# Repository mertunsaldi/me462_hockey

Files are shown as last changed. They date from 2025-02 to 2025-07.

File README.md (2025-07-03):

# me462_hockey

## Hafta puanları

| Weeks | Date | Mert | Fatih | Tuna | Seçkin | Bekirhan |
|---|---|---|---|---|---|---|
| 3 | 06.03.2025 | 4 | 4 | 4 | 4 | 4 |
| 4 | 13.03.2025 | 7.5  | 6.5 | 6 | 7.5 | 7.5 |
| 5 | 20.03.2025 | 6  | 6 | 6 | 6 | 6.5 |
| 6 | 27.03.2025 |  7 |  6.5  | 6.5 | 5 | 6.5 |
| 7-8 | 10.04.2025 |  5 | 4 |6 | 4 | 3 |
| 9 | 17.04.2025 |  6.5 | 7 |6.5 |  7.5 | 6 |
| 10 | 24.04.2025 |  6 | 6 |7.5 | 6 | 6 |
| 11-12 | 08.05.2025 |  7.5 | 7 | 8.5 |  7 | 7 |
| 13 | 15.05.2025 |  8 | | 9 | 7  | 9 |  
| 14 | 22.05.2025 |  7.5 | |7 | 7  | 8 |  
| | 19.06.2025 | | | 6| | 9 |

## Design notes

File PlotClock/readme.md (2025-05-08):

The original project by https://github.com/ProjectsWithRed/plotclock?tab=readme-ov-file is being modified.

To do (17.04.2025):   
  
Done:
- Try the micropython code on the real setup (tick)
- If you can't make it work after calibration, you can use ESP32 and the original code. (tick, calibration is done)
- Maybe add a 3rd dof for rotation at the end effector with another servo so that you can adjust the angle of the impact surface. (tick, seems like not needed)
- Assemble the whole mechanism and try mode 1. (tick, small design changes and modifications to code are done)
    
To be done:
- 0,0 noktasinin yerini ve workspace'ini tam olarak belirle (Hangi koseye uzanabiliyor ve konumu ne vs.) Kodda da bu duzgun bir sekilde map edilmis olmali. Workspace'im dikdortgen degil. Bir 5bar simulasyonu yapip tam olarak workspace'imi bulmaliyim. Sonra o workspace'i mi kullanicam yoksa consistent oldugu dusundugum x ve y ranglerinin icinde mi calisicam ona karar vermeliyim.
- Try going to the desired location in a simulation environment. (tick)
- Add a ball and target location to the simulation and integrate the search according to the ball and target location.
- Serial communication with the master and moving to the location (and angle of the impact surface) received by the master computer.
- Modify the design slightly. Remove the whiteboard, add legs, etc.

Notes:
- Su an 0,10 diyince y'de 0'a geliyor. 0,5 diyince servo baseini donduruyor o yuzden y=10 benim sifirim olmali. 0,10 ile  0,20 arasinda yaklasik 11mm mesafe var. Boyle bir errorum var gibi duruyor.
- Bu map range tam istedigim gibi calismiyor, tam ne ise yapiyor anlayamadim hatta cunku belli x yada y degerinin otesine gitmesini engellemiyor. Sanirim sadece potansiyometreyi daha accurate maplemek icin var.

The mechanism:


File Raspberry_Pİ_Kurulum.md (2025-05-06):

Raspberry Pi Bilgileri Ve kurulum rehberi <br>

  hostname: raspberrypi.local <br>
  username: remor <br>
  password: remor <br>

Wireless LAN
  
  SSID: Seççavv <br>
  Password: mersin3301 <br>

Kurulum ve RaspberryPi kullanma

1) Pi'a güç verin
2) Bilgisayar ve Pi'ı aynı internet ağına bağlayın
3) Bilgisayardan terminali açın ve aşağıdaki komutu girin. (username@hostname)
  ssh remor@raspberrypi.local
4) Şu an pi'ın içindesiniz.

Eğer Pi'dan masaüstü görüntüsünü almak isterseniz
1) Pi'ın masaüstü görüntüsünü almak için terminale sudo raspi-config yazın
2) Interface optionsa girip VNC serverını enablelayın
3) Internetten VNC Viewer adlı uygulamayı indirin ve kurun
4) VNC Viewera pi'ın bağlı olduğu ipyi yazarsanız kendi bilgisayarınızda pi'ın masaüstünü görebilirsiniz

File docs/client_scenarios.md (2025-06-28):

# Writing Client Scenarios

Clients may upload their own Python modules implementing custom logic. Each file must define a `ClientScenario` class derived from `ball_example.scenarios.Scenario`.

```python
from ball_example.scenarios import Scenario

class ClientScenario(Scenario):
    def update(self, detections):
        # access PlotClock helpers or run your own logic
        pass
```

Use `/load_scenario` to activate the scenario:

```bash
curl -X POST http://localhost:8000/load_scenario -H 'Content-Type: application/json' -d '{"path": "my_scenario.py"}'
```

Alternatively upload the file:

```bash
curl -X POST -F 'file=@my_scenario.py' http://localhost:8000/load_scenario
```

You can send runtime messages to the active scenario with `/send_message`:

```bash
curl -X POST http://localhost:8000/send_message -H 'Content-Type: application/json' -d '{"mode": "stop_defense"}'
```

**Security warning:** the server executes the uploaded Python code directly. Only run scenarios from trusted sources.

## Example: Standing Ball Hitter

The repository contains an example scenario in `examples/standing_hitter_client.py` which simply reuses the built-in `StandingBallHitter` logic.

1. Start the server on the host machine. You can either run the package or execute the script directly:
   ```bash
   # package form (recommended)
   python -m ball_example.app

   # or run the script directly
   python ball_example/app.py
   ```
2. From another terminal (or another machine on the same network) upload the scenario:
   ```bash
   curl -X POST -F 'file=@examples/ball_reflector_client.py' http://localhost:8000/load_scenario
   ```
3. Connect the PlotClock using the **Connect Pico** button (or POST to
   `/connect_pico`).  Ensure the Arena Manager marker (ID 0) and the PlotClock
   marker (ID 1) are visible to the camera while connecting.  Any additional
   PlotClock markers will be ignored. The button will turn green once the
   connection succeeds.
4. Open `http://<host-ip>:8000/` in a browser. After uploading the scenario,
   press **Start Scenario** (or POST to `/start_scenario`) to begin execution.
   When a scenario starts, its `on_start()` method runs. The built-in
   `StandingBallHitter` clears any previous calibration so you should see the
   calibration routine whenever you start it.  Calibration points are now
   chosen slightly inside the working area so the arm doesn't hit its
   mechanical limits.
5. Optionally send messages while it is running:
   ```bash
   curl -X POST http://localhost:8000/send_message -H 'Content-Type: application/json' -d '{"cmd": "stop"}'
   ```

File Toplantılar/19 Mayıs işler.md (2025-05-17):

19 Mayıs haftası için:

PiCam kullanma
Dİnamik takip
MAsa boyutları kararlaştırma
Mikroswitchler

Sonrası için

Plot clock yukarı almak
Plot clock link length kararlaştırmak

To do:

- plotclock buyuyecek
    - yeni linklerin boyunun belirlenmesi
        - arena boyunun yarisini taramali mesela. Bunun icin projectoru belli bir yukseklige cikarip nasil bir arena boyu olabilir denenmeli.
        - ya bekirhanin geogebrasinda ya da tunanin simulasyonda denenerek link lengthler belirlenebilir.
    - link tasarimi guncellenmesi, yeni servoya gore
    - baski
    - yeni servonun harika hanimdan alinmasi
    - assembly
    - kodda link lengthlerin guncellenmesi
    - kalibrasyonun yapilmasi ve kodun denenmesi
- plotclock daha yukari takilacak, altindan top gecip duvara carpabilmeli.
- duvar yuksekligi kisaltilacak (çok zor değil, çok gerekli de değil)
  
- microswitch ile carpma sensoru yapilcak
- top statikken detection gelistirilmeli.

Yeni hafta için yapılacaklar

Plot clock büyütme
	
	Yeni link boyutu belirlenmesi
	Kodumuz link length değişimine uygun
	Plot clockucu elektromıknatıs olabilir,

Arena Boyutumuz?
	Projektörü sigmaya eklenemk için kesim
 
 Seckin -> pi ve pi kamerasiyla detection deneyecek pazar sabahina kadar.
Mert- > Seckinden kamera ve pi devralip, pi kamerasiyla ball detection gelistirilecek.
Bekirhan, Tuna -> Arena ve yeni link boyu belirlenmesi, yeni link tasarimi, baski, assembly, ve calistirilmasi.
Fatih -> duvar yuksekligi 6cmye dusurulup uretilebildigi kadar uretilicek

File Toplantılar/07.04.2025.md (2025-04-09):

- Tuna'nın duvar tasarımına bakıldı
- Bekirhan'ın shift register demosuna bakıldı, resistor fikri incelenecek
- İş bölümü yapılacak
- Fatih'in duvar tasarımı bittikten sonra decision matrix ilenihai tasarım belirlenecek

# İş bölümü

## İşler

- Flowchart çizilecek (input output belirleme)
- Detaylı duvar tasarımı/üretimi -> Fatih, Tuna
- Bağlantı arayüzü belirleme -> Bekirhan, Seçkin
- Projeksiyon ve image beraber çalışıyor mu? Her ortamda çalışıyor mu? Çalışmazsa projeksiyonu ekarte mi etsek? -> Perşembe dersten sonra
- Gadget tasarımına başlanacak -> Tuna (5 bar robot), Seçkin, Fatih
- OOP için kod iskeleti -> Mert, Tuna
  - Classlar ve inheritance ilişkisi 
  - Methodların input outputları
  - Init parametreleri
- Touch sensor seçeneklerinin belirlenmesi -> Bekirhan, Mert

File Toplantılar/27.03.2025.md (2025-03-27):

Tarih 27.03.2025
Katılımcılar: Tüm Grup Üyeleri

Toplantı Konuşulanlar:

1) Blockly konuşuldu.

2) Plot clock hakkında konuşuldu.

3) Duvar Tasarımları:

	- Tasarım matrisi yapın ve karar verin
	- Fatihin Tasarımı
		- Hinge tasarımı düzenlenerek bağlantı ksıımalrındaki gap yok edilebilir.
	
	- Seçkinin Tasarımı
		- Oynar olması çok da önemli mi? sorusu soruldu.
		- T şeklinde duvar sıkıntı olur mu dendi.
	- Tork anahtarı çalışma mantığına bakılabilir.

	- Duvar ayakları fikri konuşuldu beğenildi.

	- Kablolama işi ic232 kullanıabilir.
	- Duvarların hepisi bağlı olması yerine her gadget etrafını okusa
	- Dirençler ile birlikte sensörler okunabilir.
	- Optik sensör kullanılabilir. ve bir köprü yapılabilir.
	
Hedefler:
- Tatil boyunca birbirinden farklı birkaç oyun için blockly denenebilir. Fikir olmaması açısından.
- Birkaç senaryo için algoritma çıkarılacak.
- Adreslemenin nasıl yapılacağı belirlenecek
 - Shift register
 - Farklı resistorler, farklı duvarlara
 - Gadgetlara da pico ekleyip zinciri her bir picodan sonra tekrar oluşturmak
- Duvar Tasarımını belirlenecek artık. tasarım matrisi yapılacak.
- Yazılım kısmına başlanacak

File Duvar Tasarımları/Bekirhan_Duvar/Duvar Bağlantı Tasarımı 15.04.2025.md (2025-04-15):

# Genel Güç Hattı
- 5V ve GND kabloları tüm duvarların içinden geçerek birbirleriyle bağlanacak.

# Actuatör Bağlantı Sistemi Tasarımı

## 1. Her actuatörün kendi mikroişlemcisi olacak.
- Mikroişlemci yalnızca ana bilgisayara bağlanacak.
- Tercihen sadece iki ekstra kablo ile bağlantı yapılabilecek (I2C ya da UART gibi; 5V ve GND zaten mevcut) ya da WiFi ile kablosuz bağlantı sağlanabilir (ancak hız yeterli olur mu???).

## 2. Her actuatör arenanın ana işlemcisi ile hareket ettirilecek.
- Kablolama daha karmaşık olacaktır, ancak SIPO tipi bir shift register kullanılabilir. Böylece tüm actuatörler minimum kablo sayısı ile kontrol edilebilir.
- SIPO ile PWM kontrolü verimli olmayabilir. Sinyalin manuel olarak PWM şeklinde oluşturulması gerekebilir.

## Sonuç
- Her actuatörün bir mikroişlemcisi olmasına karar verdik. Bunun sebebi, projenin bir eğitim ortamı oluşturmayı amaçlamasıdır. Böylece yeni bir gadget tasarımı, arena tasarımından mümkün olduğunca bağımsız şekilde yapılabilir.

## Mikroişlemciler Arasında Kablolu mu, Kablosuz Bir İletişim mi Kullanmalıyız?
- Her ne kadar hızlı bir top hareketi hedeflenmese de, topa vurma aksiyonunun gecikmeli olmasını istemiyoruz. Geçmiş deneyimlerden (örneğin ME461 projesi) WiFi’ın yeterli hıza ulaşamadığı anlaşılmış ve bu nedenle kablolu tasarım tercih edilmiştir.
- Kablolu haberleşme, WiFi seçeneğini tamamen dışlamaz. İstenirse her iki yöntem de uygulanabilir.

## Mikroişlemciler Arasında Hangi İletişim Protokolü Kullanılmalı?
- İlk başta I2C düşünülmüş, fakat yapılan araştırmalar sonucunda I2C’nin uzun kablolarda sorun çıkardığı öğrenilmiştir.
- UART da bir seçenek olarak değerlendirilebilir. Ayrıca yapay zekâ (AI) tarafından RS485 modülü kullanılması önerilmiştir.
- Nihayetinde, sadece 2 kablo ile tüm mikroişlemcileri birbirine bağlamak mümkün görünmektedir.

# Çarpma Sensörü Bağlantı Tasarımı

## Microswitch ya da 1/0 sinyali üreten başka bir birim kullanılacak.
- PISO tipi shift register kullanımı, 10.04.2025 tarihli toplantıda kabul edilmiştir.
- Load, Clock ve Data olmak üzere 3 kablo hattına ihtiyaç vardır.
- Bu hatlar aracılığıyla 1 ve 0 sinyali üreten diğer sensörler de okunabilir. Örneğin,daha önce konuşıulan içinden geçen topu temassız algılayan kızılötesi sensör de bu hatla okunabilir.

# Sonuç

- 5V, GND, Load, Clock, Data, ActuatorCom1 ve ActuatorCom2 olmak üzere minimum 7 adet kabloya ihtiyaç duyulmaktadır.

## T Şeklindeki Duvar Bağlantısı Sorunu

- Daisy-chain bağlantı yapısı tercih edildiğinden, bu yapı üçlü bağlantıyı (özellikle sensör veri kablosu için) desteklememektedir. Bu nedenle aşağıdaki alternatif çözüm yöntemleri değerlendirilmiştir:

### 1. İç Duvarlara Sensör Veri Kablosu Koymamak
- Adından da anlaşılacağı üzere, "sorunları sorun etmezsen sorun kalmaz" yaklaşımıdır.
- Ancak bu yaklaşım, iç duvarlardaki sensör verilerini alamamayı göze alır.

### 2. Sırt Sırta 2 Duvar Kullanarak İç Kısımlara Girmek
- Basit ve efektif bir yöntemdir.
- Ancak bu durumda ilgili bölgedeki duvar kalınlığı artacak ve bu durum simetrik bir duvar tasarımını desteklemeyebilir.

### 3. Sensör Veri Kablosu Sayısını Bir Adet Arttırıp Giriş-Çıkış Yapmak
- İç kısma giden duvarda iki veri kablosu kullanılıp, en uç noktada bu iki kablo birleştirilerek “U” yapısı oluşturulur.
- Bu şekilde toplamda 8 kabloya sahip olunur (bu sayı, konektör standardizasyonu açısından da daha uygun olabilir).
- Sıklıkla kullanılmayan bu ekstra kablo, gelecekte farklı amaçlarla da kullanılabilir. Örneğin:
  - İki duvarlı bir gadget tasarımında, bir mikroişlemci ile diğer duvardaki bir servo motor kontrol edilebilir.

##  Ada Şeklindeki Duvar Bağlantı Sorunu
- Daisy chain yapısı nedeniyle, arenanın dış duvarlarıyla fiziksel bağlantısı olmayan “ada” tipi duvarlar sıkıntı yaratmakta.
### 1. Ada duvarlarında gadget veya sensör olmasın
  - Düşünülebilir ama meh gibi de

### 2. Köprü denen bağlantı elemanı
  - Yalnızca kablo bağlantısı için duvarları birbirine bağlayan altından topun geçmesine müsade eden bir eleman
    
# Connector Seçimi
- Her duvarı birleştiren konnectör ve duvarın üstündeki gadget ve sensör bağlantı connectörü aynı cins olabilir böylece karşıklığın önüne geçmiş oluruz.
- Duvarla T çiziyorsak eğer her duvarı bir öncekine bağlamamız yeterli eğer ekstra data kablosu kullanılacaksa y yapılan yerdeki konnectörün fakrlı olması gerekecek.
- Her duvara çarpma sensörü eklenebielcekmiş gibi tasarım yaptığımızdan dolayı eğer duvarda sensör takılı değilse duvarın sağı ve soluna bağlanan data kablosu shortlanmalı. Eğer duvarda gadget ve sensör yoksa basit bir U şekilnde pin takılı kalabilir.
- Gadgetlar yalnızca 4 (eğer ekstra kablo da dahil edilecekse 5) pine ihtiyaç duyuyor. Duvarın üstündeki 8 pine geçebilen 4 pinli bir yapı düşünülebilir (OverEnginnering olabilir)

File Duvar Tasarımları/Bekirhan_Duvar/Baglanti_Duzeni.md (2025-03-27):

Amaç: Modüler bir duvar sisteminin sensör ve actuatörleri için uygun bağlantı yöntemimi bulmak.

Gereklilikler:
- Karışıklılığı ve gelecekteki kullanımının kolaylaştırılması için kablo sayısının azaltılması.

Çözüm Önerileri:
1) Her sensör ve actuatöre micrprocessörden bir kablo çekmek (Kötü çözüm. her duvar arasında 15-20 pinlik bağlantı gerekir ve hangi sensörün hangi kabloya takıldığını kontrol etmek zor.)
2) Shift register kullanarak az bir bağlantı sayısıyla işi hallettmek.

---
Shift Register kullanımı
  - 2 Çeşit shift register var piso (Parallel input serial output) ve sipo (Serial input parallel output)
  - Piso type birden fazla sensörü tek bir gpio pin ile okumaya yarıyor. Her bir clock sinyalinde paralel olarak yüklenmiş sinyal sırasıyla serial outputa iletiliyor.
      - Her bir duvarın içine bir adet piso type shift register konularak tüm sensörleri 3 kabloyla okuyabiliriz. (data, clock, load). 
  - Sipo type ile de birden fazla actuatör kontrol edilebilir. Maalesef pwm sinyali kullanılmak isteendiğinde manuel olarak oluşturulmak gerekecek.
      - Pwm kullanılmak istenirse PCA9685 16 Kanal i2c PWM/Servo Sürücü gibi bir sürücü kullanılabilir ama her gadget için bir tane kullanmak pahalı olabilir.

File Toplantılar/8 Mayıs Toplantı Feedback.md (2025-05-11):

8 Mayıs Toplantı Feedbacki

Duvar tasarımı onaylandı

Projeksiyonlu ve projeksiyonsuz usecaseler nasıl olabilir?
	Projeksiyon çok yukarıda olması gerektiği için ne yapabiliriz diye düşünüldü
		çünkü fiziksel zorluklar var
	
Alta ekran olsa nasıl olacak?
		ekran daha net olucak

Raspberry Pi konuşuldu

Simulasyon konuşuldu
	Hoca beğedndi
Görüntü işleme konuşuldu		

Elimizde ne varsa onun senaryosunu çıkarmaya çalışalım

Haftaya hedefimiz:

* Statik bir top duruyor, istediğimiz yere koyuyoruz
* Hedef Aruco marker veriliyor
* Plot clock ona göre vuruyor
* Eğer aruco markerın içine girerse kazanmış oluyoruz

19 Mayıs Hedefimiz

* Dinamik sistemi vurmak 

Sigmaları masaya geçirelim, öyle ilerleyelim

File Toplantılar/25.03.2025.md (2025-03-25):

Toplantı Başlangıç Saati 18:00
Toplantı Bitiş Saati 19:45
Toplantı Katılımcıları:
Bekirhan Canbaba
Fatih Can
Mert Ünsaldı
Tuna Kızal
Seçkin Eroğlu

			Toplantı Konuları

			1) Duvar Tasarımlarının Değerlendirilmesi
			2) Google blockly hakkında bilgilendirilme.

1) Duvar Tasarımlarının Değerlendirilmesi

a) Seçkinin RIGID tasarımı
	Seçkinin tasarımı rigid + ama flexible değil mecazen o kadar esnek bir tasarım değil. Farklı açıda birleşimler için oan göre önceden tasarlanmış duvara ihtiyaç var.

b) Fatihin Tasarımı
	Her açıya uygun duvar tasarımı, Duvar bileşim yerlerinde gap var düz olması tercih edilir. Elektrik bağlantısı daha belirlenmemiş.

c) Mertin Tasarımı
	Hem bağlantı elemanı hem de kablo için bir arayüz. Farklı açılara uyumlu ama Fatihinkinde olduğu gibi duvar birleşim yerlerinde gapler var.

d) Bekirin Tasarımı
	Ölü doğdu Fatihinki tüm özelliklerini zaten karşılıyor.

Arada boşluk kalma sorununa continious piano hinge: Sorunu diğer tarafa açılmıyor

2) Google blockly hakkında bilgilendirilme.
Mert bakmış lakin düşünüldüğü kadar implemente etmesi kolay değilmiş. Node-Red adında aynı mantıkla çalışan başka bir program varmış. İlerde bakılacak. 

Hedefler:
1) Shift Register ile daisy chain işi araştıralacak.
2) Fatihin modüler ayak fikrine bakılcak. Böylece birden fazla yüzey (sigma profile mdf gibi)
3) Plot clock alternatifleri araştırılacak

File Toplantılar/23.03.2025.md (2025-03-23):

Toplantı Başlangıç Saati 12.00

Toplantı Bitiş Saati 13.20

Toplantı Katılımcıları:
- Bekirhan Canbaba
- Fatih Can
- Mert Ünsaldı
- Tuna Kızal
- Seçkin Eroğlu

Toplanti Konulari:
- Sensörlerin belirlenmesi
- Konnektör tasarımı hakkında fikirler
- Duvar tasarımı hakkına fikirler
- Bu hafta için iş bölümü

## Duvar tasarımları
- Düz duvar ve içinde elektronik olan duvarlar ayrı ayrı olabilir
- İçinde elektronik olan tek bir duvar yapılıp içi boş da basılabilir
- Ayaklar modüler olabilir

## Sensörler

- Haptic/impact sensörü takılıp çıkarılabilir yapılabilir.
- Hazır sensörler araştırılacak
- Kendimiz sensör yapabilir miyiz?

## Konnektör tasarımları
- Pogo connectors
- Konnektör açıları sabit tutulup duvarlar açılı basılabilir
- Yukarıdan ters U şeklinde 

## Bu hafta için iş bölümü

Mert: Blockly
Seçkin, Bekirhan, Fatih, Tuna: Duvar
Bekirhan: Top yuvarlayacak

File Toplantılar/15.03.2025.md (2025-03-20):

Toplantı Başlangıç Saati 15.30

Toplantı Bitiş Saati 18:15

Toplantı Katılımcıları:
- Bekirhan Canbaba
- Fatih Can
- Mert Ünsaldı
- Tuna Kızal
- Seçkin Eroğlu

Toplanti Konulari:
- Top ve puck karsilastirmasi
- Gecen yilin air hockey masasinin detayli incelenmesi

Ball advantages:
-	Degisken yuzeylerde kullanilabilir
-	Air’ a gerek yok (pompa/fan, delikli ve duz yuzeye gerek kalmiyor). Air hockey table yapmak gorece buyuk bir is.
-	Farki kutlelerde top kullanimi puck’a gore daha rahat
-	Belki iste

Ball disadvantages:
-	Arenadan disari cikabilir
-	Tam ortadan vurulmadigi surece spin alabilir ve bu spin sekmeleri hesaplamayi zorlastiriyor.
-	Puck’da yaptigmiz gibi dead zone olusturmak daha zor. Belki magnetic bir sey ile yapilabilir. (Bakugan :D)
-	Duvara carpinca donme yonu tam tersine donuyor, enerji kaybi.

Puck advantages:
-	Surtunmesiz yuzey, daha uzun mesafeler kat edilebilir
-	Silindire vurmak daha kolay, cunku silindirin merkezine herhangi bir yukseklikte vurabilirsin. Topa gore daha cok vurma yerin var.

Puck disadvantages:
-	Masa gerekiyor!!! -> table’s disadvantages demek aslinda
-	Variable surtunme yapamiyorsun.

Brainstorming:
-	Duvarlarin arasindaki alanin egimi mukemmel olmayabilir. Bunu search algorithmasina entegre etmemiz gerekebilir. Bunun icin duvarlara egimi olcebilecegimiz sensorler entegre ederiz (mesela karsilikli 4 duvara) ve measurmentlari kullanarak belli bolgelerin egimlerini algoritmaya entergre edebiliriz. 
-	Yuzeyin surtunme katsayisini ogrenmek icin bir deneme atisi yapilabilir. Topu iteriz ve durma suresine gore surtunme katsayisi hakkinda bilgimiz olmus olur.
-	Duvar nasil yerde sabit duracak?
o	Vakum aparati (vantuz gibi bir sey) -> her yuzeyde kullanilamaz
o	Agirlik eklemek
o	Dis tarafinda bir cikinti, darbe geldigin
o	Laptop altlarindaki padler  ya da multi-layer cift tarafli bant
-	Telescopic ayaklari olan kameranin yerlestirilecegi U seklinde bir kamera tutacagi. U’nun her kenarinin uzunlugunun ayarlanabilmesi gerekiyor, arenanin boyutunu degistirmek istiyorsak.
-	Duvarlarin mockup tasarimlarinin dusunulmesi gerekiyor. Electrical and physical connections etc. 
-	Duvara top carpti, peki hangi duvara carpti bunu nasil anlayacagiz? Bunun icin neopixel strip mantigi kullanilabilir.
-	Spin cok buyuk sorun cikartirsa ball transfer unit kullanilarak bir objeyi de kullanabiliriz. 
-	Google blockly kullanarak oyun, arena set-up isleri halledilebilir. GUI’de duvarlari yerlestirdikten sonra istedigimiz modulun ustune surukle birakla gadget atayabiliriz. 
-

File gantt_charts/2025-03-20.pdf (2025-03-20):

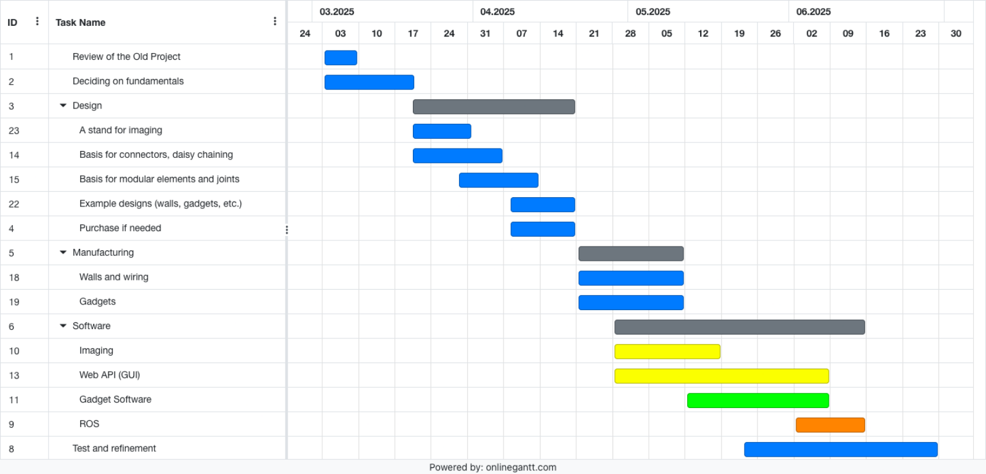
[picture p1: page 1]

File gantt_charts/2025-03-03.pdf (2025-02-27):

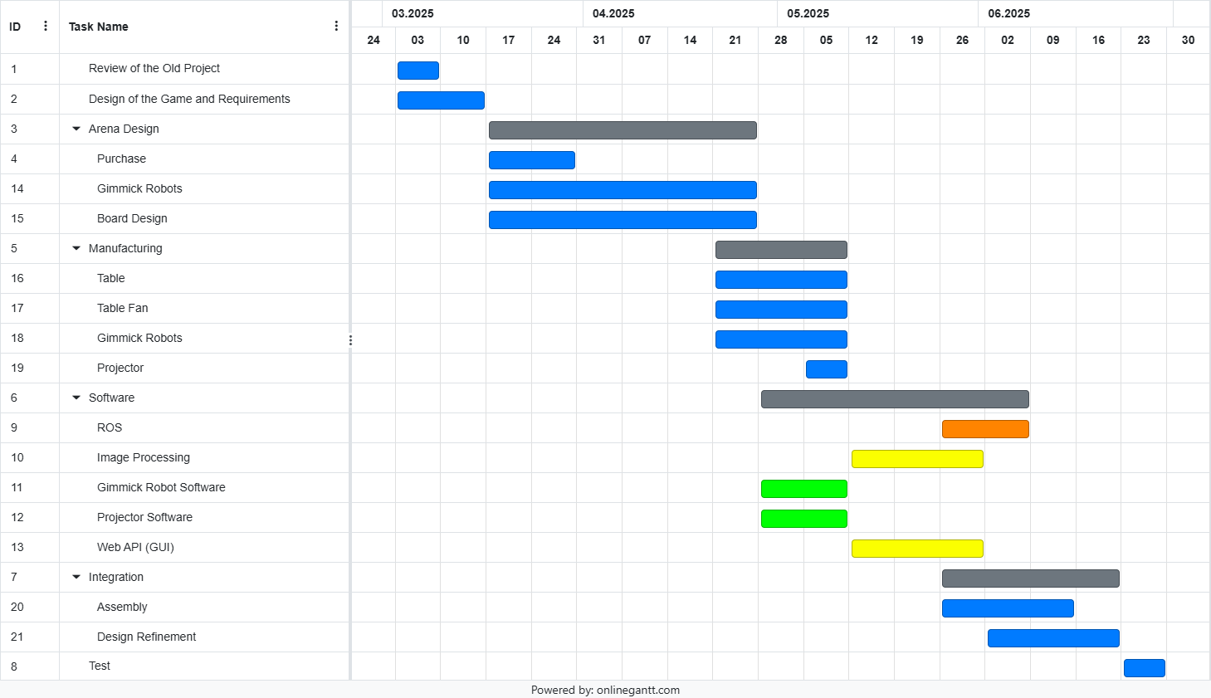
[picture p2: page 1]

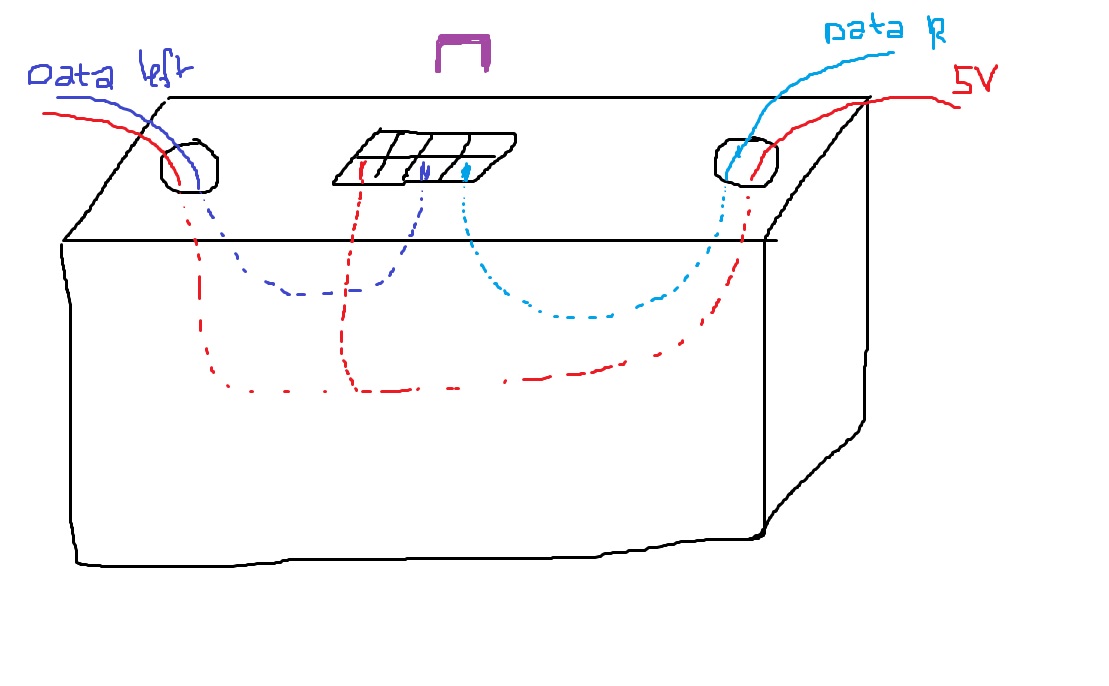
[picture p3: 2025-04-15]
Duvar Tasarımları/Bekirhan_Duvar/DuvarBaglantiOrnegi.jpg

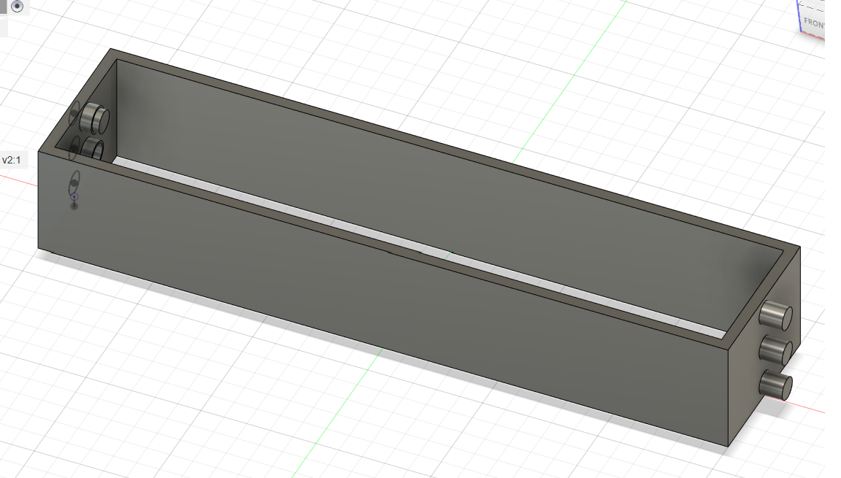
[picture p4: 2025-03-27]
Duvar Tasarımları/Seckin/Duvar.png

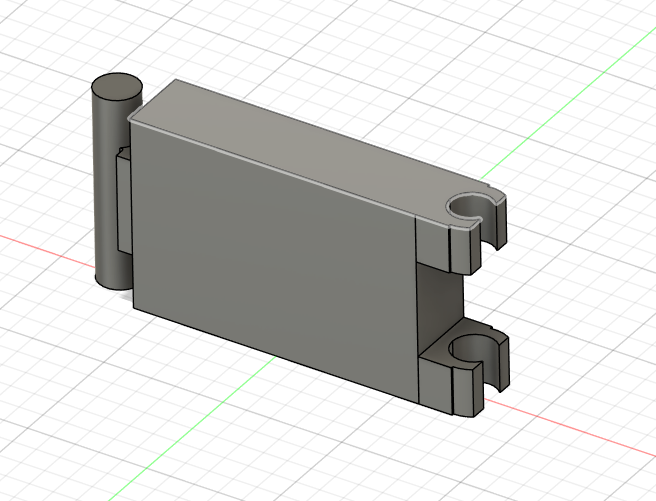
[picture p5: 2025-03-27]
Duvar Tasarımları/Fatih/TEk_iso.png

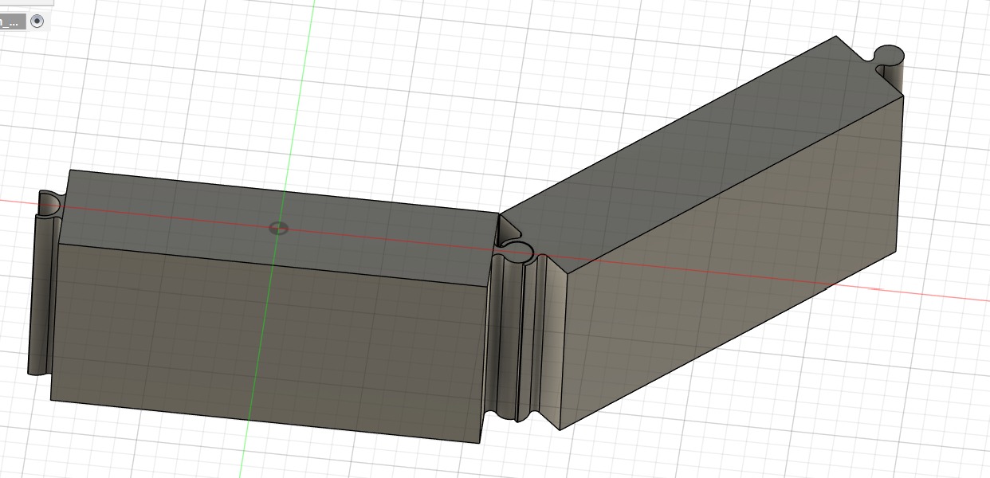
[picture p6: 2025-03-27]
Duvar Tasarımları/Bekirhan_Duvar/Bekirhan_Duvar_Tasarimi/Duvar_Tasarimi_Bekirin_Fikri_Iso_View.jpg

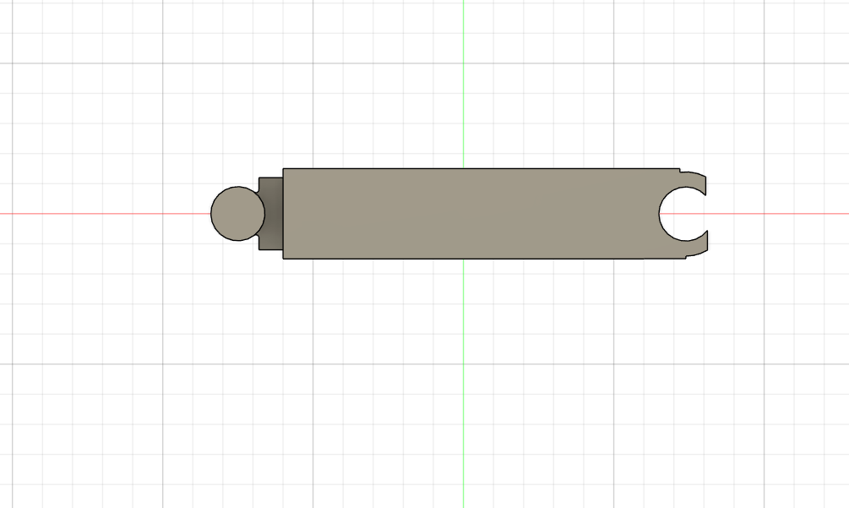
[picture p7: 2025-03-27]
Duvar Tasarımları/Fatih/tek_top.png

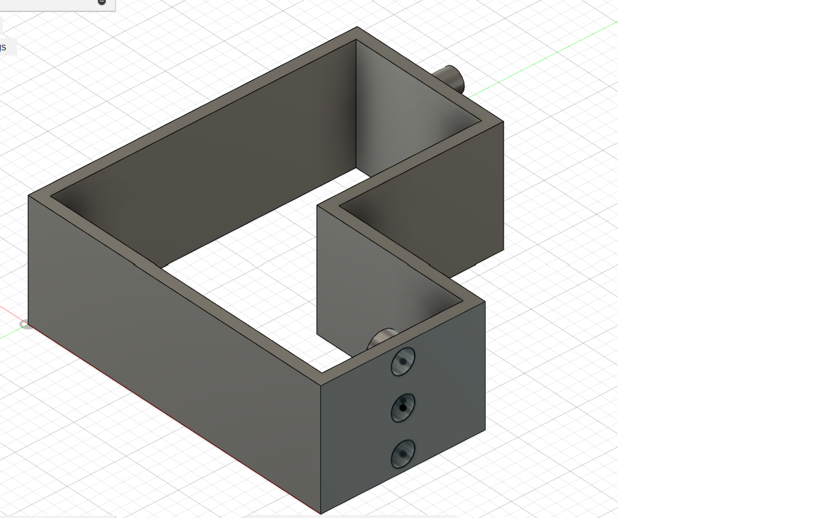
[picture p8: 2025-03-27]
Duvar Tasarımları/Seckin/Kose.png

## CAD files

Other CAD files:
PlotClockDesign/BigPlotClock/LinkHead.f3d
PlotClockDesign/BigPlotClock/servoHolderParametrized.f3z
PlotClockDesign/SmallPlotClock/PlotClockServoHolder v2.f3d
PlotClockDesign/SmallPlotClock/SmallPCLink.f3d

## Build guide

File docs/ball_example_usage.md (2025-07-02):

# Ball Example Overview

This document explains how to use the `ball_example` module, how to run the provided Flask server, and how you can build your own user interface and scenarios. After reading this guide you should be able to develop a new application around the core API.

## Running the Server

The repository ships with a ready-to-use Flask application located in `ball_example/app.py`. Start it either as a module or by executing the script directly:

```bash
python -m ball_example.app     
# or
python ball_example/app.py
```

By default the server listens on `{your_ip}:8000` and begins processing frames from camera index 0. The web interface served at `/` shows the live video with all detections overlaid. Also, `{your_ip}:8000/debug` shows information about detections and object properties.

Note: `{your_ip}:8000/tune` shows a masked frame, which does NOT represent the one used for detecting balls.

The server exposes several endpoints used by the JavaScript front end (see `templates/` and `static/`). The most important ones are:

- `POST /connect_pico` – scan for PlotClock devices and build the default scenario when marker 0 and 1 are present.
- `POST /start_scenario` – activate whichever scenario was previously loaded.
- `POST /stop_scenario` – stop the running scenario.
- `POST /load_commands` – load a list of high level commands.
- `POST /load_scenario` – load a Python file defining a `ClientScenario` (see below).
- `POST /send_message` – send an ad-hoc message to the active scenario.
- `GET /debug_data` – retrieve extended diagnostics returned by `GameAPI.debug_info()`.

Refer to `docs/api_testing_guide.md` for examples of how to call these endpoints from another machine.

### Example Workflow

1. Flash `PlotClockMaster.py` to the master Pico and the appropriate
   firmware (`PlotClockSlave.py` or `arena_manager_slave.py`) to each
   device.
2. Connect the master Pico to your PC via USB and run the server:

   ```bash
   python -m ball_example.app
   ```
3. Use the web UI or POST to `/connect_pico` to detect the attached
   devices.
4. Upload a command list with `/load_commands` or a custom scenario with
   `/load_scenario`.
5. Start execution via `/start_scenario` and open
   `http://<host-ip>:8000/` in your browser to view the stream and
   overlays.

## Key Classes

### `GameAPI`

`GameAPI` owns the camera, tracking pipelines and the currently active scenario. The Flask app only acts as a thin wrapper around this class. Important methods include:

- `start()` – start the camera and pipelines.
- `set_cam_source(src, width, height, fourcc)` – switch the camera source.
- `connect_pico()` – open the serial connection to the Pico master and detect PlotClocks.
- `load_commands(commands)` – create a `CommandScenario` from a list of dictionaries.
- `load_scenario(path)` – load a Python module that defines `ClientScenario`.
- `start_scenario()` / `stop_scenario()` – control the currently loaded scenario.
- `start_clock_mode(clock, mode, target_mm)` – start an action like `attack`, `defend` or `hit_standing` for a single PlotClock.
- `start_move_object(manager, obj, target_mm)` – create a `MoveObject` scenario to move a ball or obstacle.
- `debug_info()` – return dictionaries describing all detections and parameters.

A GUI can simply instantiate `GameAPI`, call `start()` and then display `get_annotated_frame()` in a loop.

### `PlotClock` and `ArenaManager`

Both classes live in `ball_example/gadgets.py` and encapsulate communication with the robot hardware. `PlotClock` controls a hitting arm while `ArenaManager` can also grip and move objects. Their `calibrate()` methods expect lists of ArUco detections and drive the internal calibration FSM.

Useful helpers are:

- `send_command(cmd)` – send raw firmware commands.
- `pixel_to_mm()` / `mm_to_pixel()` – convert between image pixels and robot coordinates once calibrated.
- `draw_working_area(frame)` – draw the reachable polygon for visualisation.
- Behaviour helpers such as `attack()`, `defend()` and `hit_standing_ball()` which construct corresponding scenarios.

### Scenarios

Every scenario derives from the base class `ball_example.scenarios.Scenario` which defines the lifecycle hooks:

```python
class Scenario:
    finished: bool = False
    def on_start(self):
        pass
    def on_stop(self):
        pass
    def process_message(self, message: dict):
        pass
    def update(self, detections):
        raise NotImplementedError
```

Built-in scenarios in `scenarios.py` implement more complex behaviours. Notable ones are:

- `MoveBallHitRandom` – moves the ball to the hitter and then strikes it toward a random target.
- `StandingBallHitter` and `SingleHitStandingBallHitter` – wait for a ball to stop then hit it toward a provided point.
- `BallReflector` – defend the goal by reflecting incoming balls.
- `MoveObject` – used by `ArenaManager` to grab and place objects.

All scenarios provide overlay callbacks (`get_line_points`, `get_extra_points`, `get_extra_labels`) used by the web UI for drawing helper graphics.

## Writing Your Own Scenario

Create a new Python file defining a subclass named `ClientScenario`. You can import any helpers from `ball_example`:

```python
from ball_example.scenarios import Scenario
from ball_example.gadgets import PlotClock

class ClientScenario(Scenario):
    def __init__(self, clock: PlotClock, frame_size):
        self.clock = clock
        self.frame_size = frame_size

    def update(self, detections):
        # Implement your frame logic here
        pass
```

Load the file at runtime using:

```bash
curl -X POST http://localhost:8000/load_scenario -F 'file=@myscenario.py'
```

Then start it via `/start_scenario`.

For inspiration check the implementation of `MoveBallHitRandom` in `ball_example/scenarios.py`.

## Building a Custom GUI

`app.py` demonstrates how to wire `GameAPI` into a Flask web interface. A user can develop their own GUI by creating a small program that imports `GameAPI` and periodically fetches frames. The minimal loop looks like:

```python
from ball_example.game_api import GameAPI

api = GameAPI()
api.start()

while True:
    frame = api.get_annotated_frame()
    if frame is not None:
        # show frame using cv2.imshow or any GUI toolkit
        pass
```

You are free to design a completely different interface, e.g. using `tkinter` or `PyQt`. Just call the methods on `GameAPI` to move the PlotClocks and trigger scenarios as needed. One may take a look at demo files under `/examples` folder, they provide simple features using tkinter.

## Firmware and Calibration Scripts

The hardware is driven by a pair of Raspberry Pi Pico boards. The repository contains MicroPython firmware for these devices inside the `PlotClock` directory:

- `PlotClockMaster.py` – runs on the **master** Pico. It simply forwards all serial commands from the host to the slave board via UART and echoes back any replies. Flash this file onto the Pico connected to the host PC.
- `PlotClockSlave.py` – firmware for a PlotClock robot. It decodes commands such as `p.getMinY()` or `p.setXY()` and sends a script back or drives the servos accordingly. Deploy it to the Pico attached to the hitter plotclock.
- `arena_manager_slave.py` – similar to the PlotClock slave but controls the **Arena Manager** with the gripper. Flash this on the Pico driving the manager mechanism.

Use a tool like `mpremote` or `rshell` or `Thonny` to copy the scripts to the respective boards, naming them `main.py`. The master Pico appears as a USB serial device on the host machine while the slave Pico is connected only to the master via UART.

Calibration of the arena manager is performed with `calibration_map.py`. Execute
this script on the host after connecting the devices. It builds a grid of points
inside the working area, moves the manager to each one and records the resulting
image coordinates. Once complete it writes `calibration_map.csv` and
`calibration_poly.csv` which are loaded automatically by `ArenaManager`. Optionally, one may also test how the calibration turned out via `Go to Corrected Points` button.

Note: It is necessary for the camera to see all the arena corners (4x4 Aruco markers of id 13).

### Calibration Logic

`PlotClock` and `ArenaManager` share a simple calibration procedure used to
translate between image pixels and millimetres. Each `PlotClock` moves to three
pre-defined points within its workspace. After every move the ArUco marker on
the hitter is detected and the pixel centre stored. Once all three positions are
captured the unit vectors `u_x` and `u_y` describing the x and y axes are
computed. The calibration also determines the pixel origin so the following
relation holds:

```text
pixel = origin + u_x * x_mm + u_y * y_mm
```

`mm_to_pixel()` and `pixel_to_mm()` simply evaluate this expression (or its
inverse) to convert coordinates.

For the arena manager the orientation is derived from two servo markers
(`id 47`) and the manager marker (`id 0`). The helper function
`compute_servo_transform()` in `calibration_map.py` calculates the same
`origin`, `u_x` and `u_y` vectors from those three detections before the regular
calibration routine begins.

`calibration_map.py` then commands the manager through a series of grid points
covering the allowed polygon. For each point the measured pixel location is
converted back to millimetres and stored in `calibration_map.csv`. The script
fits a 2D quadratic polynomial that maps measured positions to commanded targets.
Its coefficients are written to `calibration_poly.csv` and loaded automatically
by `ArenaManager` for future corrections.

## Putting It All Together

Below is a more detailed outline of the typical order in which `GameAPI` methods are called when building an application similar to `app.py`.  The comments show which calls are performed once during setup and which run repeatedly inside the main loop:

```python
from ball_example.game_api import GameAPI

api = GameAPI()
api.set_cam_source(0, width=1280, height=720, fourcc="MJPG")
api.start()                 # start camera and tracking        (one time)
api.connect_pico()          # open the serial link to the master Pico  (one time)

# Either load a list of commands or a custom scenario
# api.load_commands([...])
api.load_scenario("myscenario.py")

api.start_scenario()        # start running scenario           (one time)

try:
    while True:                            # main loop runs indefinitely
        frame = api.get_annotated_frame()
        if frame is not None:
            display(frame)  # e.g. cv2.imshow or any GUI toolkit
        # optionally send api.send_message(), api.debug_info(), ...
        # repeated logic goes here
except KeyboardInterrupt:
    pass
finally:
    api.stop_scenario()     # once, when exiting
```

This structure lets you build GUIs in any framework. All high level behaviour is exposed through `GameAPI`.

## Other Important Modules

The project contains several helper modules that can simplify
development:

- `high_level.py` – convenience functions such as
  `discover_plotclocks`, `calibrate_clocks` and `draw_arena` which are
  useful when writing small scripts.
- `simple_api.py` – interprets a list of action dictionaries and runs
  them sequentially using the `CommandScenario` class.
- `detectors.py` and `trackers.py` – implement ArUco and ball detection
  along with Kalman-based tracking.

## Next Steps

- Explore `docs/api_testing_guide.md` for REST examples.
- Read `docs/client_scenarios.md` for more details on uploading scenarios.
- Examine the HTML templates under `ball_example/templates/` to see how the existing UI interacts with the endpoints.

Using these pieces you should be able to extend the system and build your own applications around the ball example.

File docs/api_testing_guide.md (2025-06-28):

# API Testing Guide

This guide describes how to interact with the Flask server from another device on
your local network.

1. **Run the server**

   ```bash
   # package form (recommended)
   python -m ball_example.app

   # or run the script directly
   python ball_example/app.py
   ```
   The server listens on port `8000` by default.

2. **Discover the host IP**

   On the machine running the server, determine its local IP address.  You can
   use `ip addr` on Linux or `ipconfig` on Windows.  Suppose the address is
   `192.168.1.100`.

3. **Connect the PlotClock**

   Use the **Connect Pico** button on the web page or POST to `/connect_pico`.
   Make sure the Arena Manager marker (ID 0) and the PlotClock marker (ID 1) are
   clearly visible to the camera.  Any additional PlotClock markers will be
   ignored during calibration:

   ```bash
   curl -X POST http://192.168.1.100:8000/connect_pico
   ```

4. **Send commands from another device**

   On another computer connected to the same network, you can use `curl` or a
   small Python script to post commands.  Below is an example using `curl`:

   ```bash
   curl -X POST http://192.168.1.100:8000/load_commands \
        -H 'Content-Type: application/json' \
        -d '{"commands": [{"action": "calibrate", "clock": 0}]}'
   ```

   Or using Python:

   ```python
   import requests
   url = 'http://192.168.1.100:8000/load_commands'
   data = {"commands": [{"action": "calibrate", "clock": 0}]}
   r = requests.post(url, json=data)
   print(r.json())
   ```

5. **Load a Python scenario**

   ```bash
   curl -X POST http://192.168.1.100:8000/load_scenario -H 'Content-Type: application/json' \
        -d '{"path": "myscenario.py"}'
   ```

6. **Start the scenario**

   ```bash
   curl -X POST http://192.168.1.100:8000/start_scenario
   ```

   After the scenario is running you can send messages:

   ```bash
   curl -X POST http://192.168.1.100:8000/send_message \
        -H 'Content-Type: application/json' -d '{"cmd": "stop"}'
   ```

7. **Video stream**

Navigate to `http://192.168.1.100:8000/` in a browser to view the live
   camera feed and overlay.

8. **Retrieve debug information**

   ```bash
   curl http://192.168.1.100:8000/debug_data
   ```

   This endpoint exposes all diagnostics from `GameAPI.debug_info`,
   including `ball_details` and image processing parameters.

Only trusted clients should be allowed to issue commands, as they can control the
connected PlotClocks.

## Python helper module

For quick scripting you can import helper functions directly from the project
root:

```python
from high_level import discover_plotclocks, calibrate_clocks
```

These wrappers simplify PlotClock discovery and calibration when using the
`GameAPI` class programmatically.

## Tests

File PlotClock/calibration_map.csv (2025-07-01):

cmd_x_mm | cmd_y_mm | px_x | px_y
-287.91580885294434 | 160.68148882082627 | -388.4307860529316 | 199.44804949234705
-221.56152437812725 | 160.68148882082627 | -309.3482901279692 | 201.16817689411465
-155.20723990331015 | 160.68148882082627 | -217.01069481291537 | 199.8383304994708
-88.85295542849306 | 160.68148882082627 | -118.47196794022875 | 195.9499752803491
43.85561352114112 | 160.68148882082627 | 44.434215403643634 | 161.63415635769132
110.20989799595822 | 160.68148882082627 | 126.13303956154662 | 182.59369192544776
176.5641824707753 | 160.68148882082627 | 216.2445876507836 | 198.14711280193458
176.5641824707753 | 227.03577329564337 | 241.00574932496755 | 299.200983942752
110.20989799595822 | 227.03577329564337 | 142.91512286786747 | 283.06936898163735
43.85561352114112 | 227.03577329564337 | 60.912746815534895 | 280.1350340021515
-22.49867095367597 | 227.03577329564337 | -22.7374823779868 | 286.1048879259331
-88.85295542849306 | 227.03577329564337 | -109.37986595945718 | 291.85791906797937
-155.20723990331015 | 227.03577329564337 | -211.90813201607537 | 295.4571772447872
-221.56152437812725 | 227.03577329564337 | -299.25880335121474 | 297.1483949423234
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

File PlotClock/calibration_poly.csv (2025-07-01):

cx0 | cx1 | cx2 | cx3 | cx4 | cx5
21.382000 | 1.113406 | -0.130706 | 0.000045 | -0.000276 | 0.000202
cy0 | cy1 | cy2 | cy3 | cy4 | cy5
46.027367 | 0.015526 | 0.839115 | -0.000070 | 0.000002 | 0.000213

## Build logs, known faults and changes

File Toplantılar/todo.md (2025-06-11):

#### Not: Yeni APInin kullanılması ile iligli rehberler docs altındaki "api_testing_guide.md" ve "client_scenarios.md" altında bulunabilir.
Şu anki örnekte (examples/ball_reflector_client.py) önceden yazılmış bir senaryoyu inherit ettim kolay deneyebilmek açısından, ama normalde bu dosya clientlar tarafından oluşturulan bir Scenario subclassını içermeli yalnızca.

- [ ] bir master pico yapılacak
  - [ ]   sensör girdilerini toplayıp bilgisayara yollayacak
  - [ ]   plotclocklara id number verilecek (hem kod içine hem aruco markera, böylece imageda gördüğümüz plotclocka hangi id ile komut vereceğimiz net olacak)
    
  - [ ]   her plotclock uart veya i2c veya wifi ile master picoya bağlanacak, pcye sadece master bağlanacak
    - [ ]     şu anda kodda gadgets.plotclock classı her bir plotclock, usb ile ayrıca bağlanıyormuş gibi yazıldı. Bu yüzden kendi port, baudrate vs. connection bilgilerini tutuyorlar, bunun değiştirilmesi gerek
          
- [ ]   dışarıdan senaryo yüklenmesi test edilecek. bir bilgisayar appi açtıktan sonra, diğer bir bilgisayar curl ile kendi senaryosunu upload edebiliyor mu?
- [ ]   senaryo yazımının basitleştirilmesi gerek

örneğin:
1) plotclockları kalibre et
2) plotclock working spacelerini çizdir
3) search algrotihm wombo jombo... -> sonuçta (x1,y1) (x2,y2) vs koordinatlar çıktığını düşünelim
4) plotclock no: 1 attack modda çalışsın gelen topu x1,y1 e atsın
5) plotclock no: 0 defence modda takılsın
6) top x2,y2 den geçerse plotclock no:1 topu x3,y3 e atsın, no:0 da x4,y4e atsın
gibi, gibi...

şu anda bizim kodumuzda plotclockların attack defence modları ayrı senaryolar halinde, her kullanıcıdan bunları baştan tanımlamasını bekleyemeyiz. 
hazır komutlar halinde sunmalıyız bazı şeyleri. onların kodunun çoğu search ve if else şeklinde olmalı

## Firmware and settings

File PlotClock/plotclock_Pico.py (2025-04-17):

import machine
import math
import time

###############################################################################
#                           PIN DEFINITIONS
###############################################################################
SERVO_LIFT_PIN = 2
SERVO_LEFT_PIN = 3
SERVO_RIGHT_PIN = 4

ENCODER_L_PIN1    = 6
ENCODER_L_PIN2    = 7
ENCODER_L_BTN_PIN = 8

ENCODER_R_PIN1    = 9
ENCODER_R_PIN2    = 10
ENCODER_R_BTN_PIN = 11

ENCODER_LIFT_PIN1    = 12
ENCODER_LIFT_PIN2    = 13
ENCODER_LIFT_INIT    = 70  # starting position (in degrees)

###############################################################################
#                       SERVO REPLACEMENT FOR "ESP32Servo"
###############################################################################
# We’ll mimic "servo.writeMicroseconds(...)" via PWM at 50 Hz.
class Servo:
    def __init__(self, pin_num):
        self.pwm = machine.PWM(machine.Pin(pin_num))
        self.pwm.freq(50)          # 50 Hz for standard servos
        self._us = 1500            # track last written microseconds

    def writeMicroseconds(self, us):
        # Clamp to safe range if needed:
        if us < 500:  us = 500
        if us > 2500: us = 2500
        self._us = us
        # Convert microseconds to 16-bit duty:
        duty = int((us / 20000.0) * 65535.0)
        self.pwm.duty_u16(duty)

###############################################################################
#                      ENCODER REPLACEMENT FOR "Encoder.h" 
#         (INTERRUPT-BASED QUADRATURE DECODING, ARDUINO-STYLE)
###############################################################################
class InterruptEncoder:
    """
    A simple quadrature encoder class using interrupts on the Pico.
    Provides a 'read()' method that returns the raw count,
    and a 'write(value)' method to set the count (like encoder.write(...) in Arduino).
    """
    def __init__(self, pinA, pinB):
        self.pinA = machine.Pin(pinA, machine.Pin.IN, machine.Pin.PULL_UP)
        self.pinB = machine.Pin(pinB, machine.Pin.IN, machine.Pin.PULL_UP)

        # current 2-bit state of the encoder
        self._state = (self.pinA.value() << 1) | self.pinB.value()
        self._position = 0

        # Attach interrupts on both edges
        self.pinA.irq(self._callback, machine.Pin.IRQ_RISING | machine.Pin.IRQ_FALLING)
        self.pinB.irq(self._callback, machine.Pin.IRQ_RISING | machine.Pin.IRQ_FALLING)

    def _callback(self, pin):
        new_state = (self.pinA.value() << 1) | self.pinB.value()
        if new_state != self._state:
            # quadrature direction logic
            if ((self._state == 0 and new_state == 1) or
                (self._state == 1 and new_state == 3) or
                (self._state == 3 and new_state == 2) or
                (self._state == 2 and new_state == 0)):
                self._position += 1
            else:
                self._position -= 1
            self._state = new_state

    def read(self):
        return self._position

    def write(self, value):
        self._position = value

###############################################################################
#                     BUTTON REPLACEMENT FOR "Button.h"
###############################################################################
class Button:
    """
    Mimics the "Button" library usage:
      - constructor (pin, debounce_ms)
      - begin()
      - pressed() to check if it was pressed since last check
    Uses a simple interrupt-based approach with minimal debounce logic.
    """
    def __init__(self, pin_num, debounce_ms=10):
        self.pin = machine.Pin(pin_num, machine.Pin.IN, machine.Pin.PULL_UP)
        self.debounce_ms = debounce_ms
        self._last_val = self.pin.value()
        self._pressed_flag = False
        self._last_change_time = time.ticks_ms()

        # Set an interrupt on both edges:
        self.pin.irq(self._callback, machine.Pin.IRQ_RISING | machine.Pin.IRQ_FALLING)

    def _callback(self, p):
        now = time.ticks_ms()
        if time.ticks_diff(now, self._last_change_time) > self.debounce_ms:
            val = p.value()
            if val == 0:
                # pressed (active low)
                self._pressed_flag = True
            self._last_val = val
            self._last_change_time = now

    def begin(self):
        # mimic the original code's usage "leftEncoderBtn.begin();"
        pass

    def pressed(self):
        if self._pressed_flag:
            self._pressed_flag = False
            return True
        return False

###############################################################################
#                          ORIGINAL CONSTANTS / VARIABLES
###############################################################################
SERVO_LEFT_FACTOR  = 630
SERVO_RIGHT_FACTOR = 640

Z_OFFSET = 230
LIFT0 = 1110 + Z_OFFSET
LIFT1 = 925  + Z_OFFSET
LIFT2 = 735  + Z_OFFSET

SERVO_LEFT_NULL  = 1950
SERVO_RIGHT_NULL = 815

WISHY = 3
LIFT_SPEED = 2000

L1 = 35.0
L2 = 55.1
L3 = 13.2
L4 = 45.0

O1X = 24.0
O1Y = -25.0
O2X = 49.0
O2Y = -25.0

HOME_X = 72.2
HOME_Y = 45.5

SCALE = 0.9
MOVE_DELAY_MS = 2

# Global servo position for lift (in microseconds for servo, initially 1500)
servoLift = 1500.0
lastX = HOME_X
lastY = HOME_Y

# 0: Calibration, 1: Encoder control (we remove auto mode)
currentMode = 1
print("currentMode: ", currentMode)
###############################################################################
#                          SERVO OBJECTS
###############################################################################
servo_lift  = Servo(SERVO_LIFT_PIN)
servo_left  = Servo(SERVO_LEFT_PIN)
servo_right = Servo(SERVO_RIGHT_PIN)

###############################################################################
#                          ENCODER OBJECTS
###############################################################################
encoderL     = InterruptEncoder(ENCODER_L_PIN1,   ENCODER_L_PIN2)
encPosL      = 0
encLastPosL  = -1

encoderR     = InterruptEncoder(ENCODER_R_PIN1,   ENCODER_R_PIN2)
encPosR      = 0
encLastPosR  = -1

encoderLift  = InterruptEncoder(ENCODER_LIFT_PIN1, ENCODER_LIFT_PIN2)
encPosLift   = 0
encLastPosLift = -1

###############################################################################
#                        BUTTON OBJECTS
###############################################################################
leftEncoderBtn  = Button(ENCODER_L_BTN_PIN, 10)
rightEncoderBtn = Button(ENCODER_R_BTN_PIN, 10)

###############################################################################
#                  Mapping Function for Lift Servo
###############################################################################
def angle_to_pulse(angle, min_angle=0, max_angle=180, min_pulse=500, max_pulse=2500):           #you should calibrate this for proper lift
    # Convert an angle (in degrees) to a pulse width in microseconds.
    return int(min_pulse + (angle - min_angle) * (max_pulse - min_pulse) / (max_angle - min_angle))

###############################################################################
#                             SETUP() EQUIVALENT
###############################################################################
def setup():
    global currentMode

    # Set initial encoder positions:
    encoderL.write(int(HOME_X * 4))
    encoderR.write(int(HOME_Y * 4))
    encoderLift.write(int(ENCODER_LIFT_INIT * 4))

    # start the button objects
    leftEncoderBtn.begin()
    rightEncoderBtn.begin()

    # If not in calibration mode (currentMode != 0), move to the home position:
    if currentMode != 0:
        lift(LIFT2)
        drawTo(HOME_X, HOME_Y)
        lift(LIFT0)

    time.sleep(2)  # delay of 2000 ms

###############################################################################
#                            LOOP() EQUIVALENT
###############################################################################
def loop():
    global currentMode

    handleEncoderBtns()

    # Calibration mode
    if currentMode == 0:
        drawTo(-3, 29.2)
        time.sleep_ms(500)
        drawTo(74.1, 28)
        time.sleep_ms(500)
    # Manual control mode
    elif currentMode == 1:
        if updateEncoder(encoderL, 'L'):
            set_XY(encPosL, encPosR)
        if updateEncoder(encoderR, 'R'):
            set_XY(encPosL, encPosR)
        if updateEncoder(encoderLift, 'Lift'):
            # Map the lift encoder value (in degrees) to microseconds.
            pulse = angle_to_pulse(encPosLift)
            servo_lift.writeMicroseconds(pulse)

###############################################################################
#                handleEncoderBtns() -- SAME LOGIC AS ORIGINAL
###############################################################################
def handleEncoderBtns():
    global currentMode
    if leftEncoderBtn.pressed():
        currentMode += 1
        if currentMode == 2:
            currentMode = 0
        print("Current mode_handle: ", currentMode)
    if rightEncoderBtn.pressed():
        erase()

###############################################################################
#            updateEncoder() -- SAME LOGIC, ADAPTED TO PYTHON
###############################################################################
def updateEncoder(enc, which):
    """
    Mimics:
      bool updateEncoder(Encoder encoder, int &encPos, int &encLastPos)
    'which' is 'L','R','Lift' to pick the correct globals.
    """
    global encPosL, encLastPosL
    global encPosR, encLastPosR
    global encPosLift, encLastPosLift

    newPos = enc.read() // 4  # Dividing by 4 as in the original code.
    changed = False

    if which == 'L':
        if newPos != encLastPosL:
            encPosL = newPos
            encLastPosL = newPos
            changed = True
    elif which == 'R':
        if newPos != encLastPosR:
            encPosR = newPos
            encLastPosR = newPos
            changed = True
    elif which == 'Lift':
        if newPos != encLastPosLift:
            encPosLift = newPos
            encLastPosLift = newPos
            changed = True
    return changed

###############################################################################
#             LIFT FUNCTION (Same Logic as Original)
###############################################################################
def lift(lift_target):
    global servoLift
    if servoLift >= lift_target:
        while servoLift >= lift_target:
            servoLift -= 1
            servo_lift.writeMicroseconds(int(servoLift))
            time.sleep_us(LIFT_SPEED)
    else:
        while servoLift <= lift_target:
            servoLift += 1
            servo_lift.writeMicroseconds(int(servoLift))
            time.sleep_us(LIFT_SPEED)

###############################################################################
#                           ERASE / DRAW / MISC FUNCTIONS
###############################################################################
def erase():
    goHome()
    lift(LIFT0)
    drawTo(70, HOME_Y)
    drawTo(65 - WISHY, HOME_Y)
    drawTo(65 - WISHY, HOME_Y)
    drawTo(5, HOME_Y)
    drawTo(5, HOME_Y)
    drawTo(63 - WISHY, 46)
    drawTo(63 - WISHY, 42)
    drawTo(5, 42)
    drawTo(5, 38)
    drawTo(63 - WISHY, 38)
    drawTo(63 - WISHY, 34)
    drawTo(5, 34)
    drawTo(5, 29)
    drawTo(6, 29)
    drawTo(65 - WISHY, 26)
    drawTo(5, 26)
    drawTo(60 - WISHY, 40)
    drawTo(HOME_X, HOME_Y)
    lift(LIFT0)

def goHome():
    lift(LIFT2)
    drawTo(HOME_X, HOME_Y)
    lift(LIFT0)
    time.sleep_ms(500)

def bogenUZS(bx, by, radius, start, ende, sqee):
    inkr = -0.05
    count = 0
    while (start + count) > ende:
        drawTo(
            sqee * radius * math.cos(start + count) + bx,
            radius * math.sin(start + count) + by
        )
        count += inkr

def bogenGZS(bx, by, radius, start, ende, sqee):
    inkr = 0.05
    count = 0
    while (start + count) <= ende:
        drawTo(
            sqee * radius * math.cos(start + count) + bx,
            radius * math.sin(start + count) + by
        )
        count += inkr

def drawTo(pX, pY):
    global lastX, lastY
    dx = pX - lastX
    dy = pY - lastY
    c = int(math.floor(7 * math.sqrt(dx * dx + dy * dy)))
    if c < 1:
        c = 1
    for i in range(c+1):
        ix = lastX + (i * dx / c)
        iy = lastY + (i * dy / c)
        set_XY(ix, iy)
        time.sleep_ms(MOVE_DELAY_MS)
    lastX = pX
    lastY = pY

def return_angle(a, b, c):
    return math.acos((a*a + c*c - b*b) / (2*a*c))

def set_XY(Tx, Ty):
    time.sleep_ms(1)
    dx = Tx - O1X
    dy = Ty - O1Y

    c  = math.sqrt(dx*dx + dy*dy)
    a1 = math.atan2(dy, dx)
    a2 = return_angle(L1, L2, c)

    servo_left.writeMicroseconds(
        int(((a2 + a1 - math.pi) * SERVO_LEFT_FACTOR) + SERVO_LEFT_NULL)
    )

    # Calculate joint arm point for the right servo.
    a2b = return_angle(L2, L1, c)
    Hx = Tx + L3 * math.cos((a1 - a2b + 0.621) + math.pi)
    Hy = Ty + L3 * math.sin((a1 - a2b + 0.621) + math.pi)

    dx2 = Hx - O2X
    dy2 = Hy - O2Y
    c2  = math.sqrt(dx2*dx2 + dy2*dy2)
    a1b = math.atan2(dy2, dx2)
    a2c = return_angle(L1, L4, c2)

    servo_right.writeMicroseconds(
        int(((a1b - a2c) * SERVO_RIGHT_FACTOR) + SERVO_RIGHT_NULL)
    )

###############################################################################
#                         MAIN BOOTSTRAP
###############################################################################
setup()

while True:
    loop()
    time.sleep_ms(10)

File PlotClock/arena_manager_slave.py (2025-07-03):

import machine
import math
import utime



utime.sleep_ms(1000	)

DEVICE_ID = "P0"

class Servo:
    def __init__(self, pin, factor = 1000, startPos = 1000):
        self.pwm = machine.PWM(machine.Pin(pin))
        self.pwm.freq(50)
        self.angle = 0 # radian
        self.factor = factor #servoFactor choosen close to 1000 and calibrate
        self.startPos = startPos #startPos choosen close to 1000 and calibrate

    def getAngle(self):
        return self.angle
    
    def writeMicroseconds(self, us):
        self.pwm.duty_u16(int(us / 20000 * 65535))

    def setAngle(self, rad):
        us = self.startPos - 500 + 2* (rad * self.factor / math.pi)
        self.writeMicroseconds(us)
        self.angle = rad

    def calibrateRotation(self,factor): 
        self.factor = factor
        self.setAngle(0)
        wait_ms(2000)
        self.setAngle(math.pi/2)
        wait_ms(2000)
        self.setAngle(math.pi)
        wait_ms(2000)

class PlotClock:
    def __init__(self,servoLeft,servoRight,L1,L2,L3,L4,hitDia,servoMarginAngle = 2.5/180*math.pi):
        self.servoLeft = servoLeft
        self.servoRight = servoRight
        self.L1 = L1    # L1: ServoLink length
        self.L2 = L2    # L2: TipLink length
        self.L3 = L3    # L3: Distance between Servos
        self.L4 = L4    # L4: Distance from servo to wall front face
        self.hitDia = hitDia # HitterDiameter
        self.servoMarginAngle = servoMarginAngle
        self.posX = 0
        self.posY = 0
        self._move_active = False
        self._last_tick = utime.ticks_ms()
        self._stepX = 0
        self._stepY = 0
        self._n_steps = 0
        self._step_index = 0
        self._stepDelay = 20

        self.gripper_servo = None

        self.initialize()
    
    def setup(self,L1,L2,L3,L4,hitDia,servoMarginAngle = 2.5/180*math.pi):
        self.L1 = L1    # L1: ServoLink length
        self.L2 = L2    # L2: TipLink length
        self.L3 = L3    # L3: Distance between Servos
        self.L4 = L4    # L4: Distance from servo to wall front face
        self.hitDia = hitDia # HitterDiameter
        self.servoMarginAngle = servoMarginAngle
        self.initialize()

    def initialize(self):
        self.O1X, self.O1Y = -self.L3/2, 0  # Left servo position (midpoint chosen as center between servos)
        self.O2X, self.O2Y = self.L3/2, 0   # Right servo position       

        beta = math.acos(self.L3 / (2 * self.L2))
        self.HOME_X, self.HOME_Y = 0, self.L1 + self.L2 * math.sin(beta)  # Home position (perpendicular servo arms)
        self.startAngle = math.asin((self.L2-self.hitDia/2-self.L4)/self.L1) + self.servoMarginAngle
        gamma = math.asin((self.L1*math.sin(self.startAngle+self.servoMarginAngle)-self.L4-self.hitDia/2)/self.L2)
        self.max_x_distance =  self.O1X + self.L1 * math.cos(self.startAngle + self.servoMarginAngle) + self.L2 * math.cos(gamma)
        self.min_y_distance = self.O1Y + self.L4 + self.hitDia/2

    def getXY (self):
        return (self.posX, self.posY)
    
    def getMaxX (self):
        return self.max_x_distance
    
    def getMinY (self):
        return  self.min_y_distance

    def getStartAngle(self):
        return self.startAngle

    def getL1(self):
        return self.L1

    def getL2(self):
        return self.L2

    def getL3(self):
        return self.L3

    def getL4(self):
        return self.L4
    
    def startPoseCalibration(self,leftStartPose,rightStartPose):
        self.servoLeft.startPose = leftStartPose
        self.servoRight.startPose = rightStartPose
        self.goHome()

    def goHome(self):

        self.gotoXY(self.HOME_X,self.HOME_Y)

    def checkTarget(self, Tx, Ty):
        dx1 = Tx - self.O1X
        dy1 = Ty - self.O1Y
        c1 = math.sqrt(dx1*dx1 + dy1*dy1)

        dx2 = Tx - self.O2X
        dy2 = Ty - self.O2Y
        c2 = math.sqrt(dx2*dx2 + dy2*dy2)

        if (c1 > self.L1 + self.L2 or c2 > self.L1 + self.L2 or abs(Tx) > self.max_x_distance
        or c1 < abs(self.L1 - self.L2) or c2 < abs(self.L1 - self.L2) or Ty < self.min_y_distance):
            #print("Point (",Tx,Ty,") is outside of the reachable area")
            return False
        return True
    
    def gotoXY(self, Tx, Ty):
    # Set Tip Point
        if self.checkTarget(Tx, Ty):
            # Calculate angle for left servo arm
            dx1 = Tx - self.O1X
            dy1 = Ty - self.O1Y
            c1 = math.sqrt(dx1*dx1 + dy1*dy1)
            a11 = math.atan2(dy1, dx1)
            a12 = cosTheomAng(self.L1, c1, self.L2) 

            # Calculate angle for right servo arm
            dx2 = Tx - self.O2X
            dy2 = Ty - self.O2Y
            c2 = math.sqrt(dx2*dx2 + dy2*dy2)
            a21 = math.atan2(dy2, dx2)
            a22 = cosTheomAng(self.L1, c2, self.L2) 

            self.servoLeft.setAngle(a11 + a12 - self.startAngle)
            self.posX = Tx
            self.servoRight.setAngle(a21 - a22 + self.startAngle)
            self.posY = Ty

    def setXY(self, Tx, Ty, n_steps=100, stepDelay=2):
        self._stepDelay = stepDelay
        self._step_index = 0
        self._stepX = (Tx-self.posX)/n_steps
        self._stepY = (Ty-self.posY)/n_steps
        self._n_steps = n_steps

    def setXYrel(self, Tx, Ty, n_steps=100, stepDelay=2):
        self._stepDelay = stepDelay
        self._step_index = 0
        self._stepX = (Tx)/n_steps
        self._stepY = (Ty)/n_steps
        self._n_steps = n_steps

        
    def move(self):
        now = utime.ticks_ms()
        if utime.ticks_diff(now, self._last_tick) >= self._stepDelay and self._step_index < self._n_steps:
            self._step_index += 1
            destX = self.posX + self._stepX
            destY = self.posY + self._stepY
            self.gotoXY(destX, destY)
            self._last_tick = now

    def update(self):
        self.move()

    def _set_gripper_angle(self, angle):
        if self.gripper_servo is None:
            return
        angle = max(0, min(180, angle))
        min_duty = 1638
        max_duty = 8192
        duty = int(min_duty + (max_duty - min_duty) * angle / 180)
        self.gripper_servo.duty_u16(duty)

    def grip(self):
        self._set_gripper_angle(50)

    def release(self):
        self._set_gripper_angle(180)

    def grip_smooth(self, end_angle=50, step=5, delay=0.01):
        if self.gripper_servo is None:
            return
        for angle in range(180, end_angle - 3, -step):
            self._set_gripper_angle(angle)
            utime.sleep(delay)

    def release_smooth(self, end_angle=180, step=2, delay=0.01):
        if self.gripper_servo is None:
            return
        for angle in range(50, end_angle + 1, step):
            self._set_gripper_angle(angle)
            utime.sleep(delay)
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

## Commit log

2025-04-10 Decision Matris
    [Decision Matrix.xlsx]
2025-04-26 calibration for 90 degrees rotation in currentMode = 0
2025-04-29 Update plotclock_pot.py
    this version works on currentMode=1 with potentiometers but there is jitter
    [plotclock_pot.py]
2025-05-03 ball tracking with opencv (consistency problems)
    [app.py, camera.py, detectors.py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]
2025-05-06 Create Raspberry_Pİ_Kurulum.md
    Altı gri caseli olan raspberry pi için kurulum rehberi
2025-05-14 plotclock's ref. frame
2025-05-22 don't know
    [Decision Matrix.xlsx]
2025-05-22 Revert "don't know"
    This reverts commit 4329c79db54840b2dd849d54e2b7a812f7be90d3.
    [Decision Matrix.xlsx]
2025-06-11 Fix scenario loader import
    [scenario_loader.py]
2025-06-11 Add files via upload
    The micropython code for the large mechanism. New calibration and inverse kinematics (new setXY) code.
2025-06-11 auto-connect to Pico when starting scenario
2025-06-11 Remove auto Pico connect
2025-06-11 Reset StandingBallHitter calibration on start
    [scenarios.py]
2025-06-15 camera settings changed
2025-06-15 lag issue on high res resolved
    [app.py, camera.py, detectors.py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]
2025-06-21 Make BallTracker thread-safe
2025-06-21 Fix calibration helper and API enhancements
    [app.py, detectors.py, gadgets.py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]
2025-06-21 Add test for GameAPI camera setter
2025-06-21 Update demos for Tkinter and raw frame usage
2025-06-21 Handle no PlotClock case in high level demo
2025-06-22 Fix relative import when running app standalone
    [app.py]
2025-06-25 fixed __all__ of high_level.py
    [high_level.py]
2025-06-25 Fix arena drawing order
    [high_level.py]
2025-06-25 Revert arena drawing to use center links
    [high_level.py]
2025-06-25 arena draw, shift test, commented out calibration on high level demo
2025-06-26 camera index changed
2025-06-26 path insert command added
2025-06-26 sys.path.insert added
2025-06-26 Fix JS error blocking buttons
2025-06-26 fix device command prefix
    [gadgets.py, scenarios.py]
2025-06-26 fix plotclock calibration by device id
    [gadgets.py, high_level.py]
2025-06-26 Extend PlotClock calibration to ArenaManager
2025-06-27 Remove scenario self calibration and wait for two clocks
2025-06-27 Query full device range for PlotClock
2025-06-28 Move calibration points inside workspace
2025-06-28 delay calibration until all clocks instantiated
2025-06-28 Calibrate manager as well
2025-06-28 Make calibration margin relative to L1
2025-06-28 Include calibration matrices in debug info
2025-06-28 Draw calibration axes
2025-06-28 default calibration points for P1 and P0
2025-06-28 hardcoded P1, P0 getters. improved marker id check for calibration
2025-06-28 scaled down, changed calibration points
2025-06-28 Calibrate all clocks
2025-06-29 Fix StandingBallHitter to use new PlotClock interface
    [scenarios.py]
2025-06-29 fix sidebar buttons after calibration
2025-06-29 Show hit start button only when hit mode active
2025-06-29 Improve UI stability and add wait pose
    [gadgets.py, scenarios.py]
2025-06-29 Avoid wait pose in defense mode
    [scenarios.py]
2025-06-29 Add missing strike timestamp
    [scenarios.py]
2025-06-29 Filter interceptor commands
2025-07-01 Implement new ArenaManager calibration
2025-07-01 Add arena manager calibration mapping script
2025-07-01 Improve calibration map grid
2025-07-01 Handle missing calibration in calibration map
    [calibration_map.py]
2025-07-01 Improve calibration map responsiveness
2025-07-01 Add feedback correction for ArenaManager
    [gadgets.py, test_manager_feedback.py]
2025-07-01 Align pixel coordinates with manager frame
2025-07-01 Fix pixel frame orientation
    [calibration_map.py]
2025-07-01 Align pixel frame orientation with updated manager calibration
2025-07-01 Fix grid point generation
    [calibration_map.py]
2025-07-01 Sort calibration grid in snake order
2025-07-01 Add polynomial regression to calibration map
2025-07-01 Use background thread for ArenaManager feedback
2025-07-01 Keep calibration window open
2025-07-01 Save polynomial coefficients and apply corrections
    [app.py, calibration_map.py, gadgets.py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]
2025-07-01 succesful aruco manager error correction from camera
    [app.py, gadgets.py]
2025-07-01 tried polynomial correction
    [calibration_map.csv, calibration_poly.csv]
2025-07-01 Fix coeffs path in app
    [app.py]
2025-07-01 added gripper.py
2025-07-02 Add gripper commands to autocomplete and adjust ball release center
2025-07-02 Add smooth gripper commands
2025-07-02 Refine smooth gripper controls
2025-07-02 Fix gripper commands and scenario
    [scenarios.py]
2025-07-02 Fix manager move checks and pipeline shutdown
    [app.py, gadgets.py, game_api.py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]
2025-07-02 Set idle positions and fix gripper commands
    [PlotClockSlave.py, arena_manager_slave.py, gadgets.py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]
2025-07-02 Handle gripper commands generically
2025-07-03 Update waiting positions and gripper smoothing
2025-07-03 Remove mask pipeline and filter balls
2025-07-03 Move obstacle overlap filter to detectors
2025-07-03 Filter obstacle overlaps during detection
